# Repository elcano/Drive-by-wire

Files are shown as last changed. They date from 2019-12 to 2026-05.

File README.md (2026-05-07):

# DriveByWire

Obsolete. New code is in DBW version 5.

This repository is for use with the **Drive by Wire** board created to be used for the ELCANO self-driving tricycle. In order for this module to run external libraries are required.

Repositories were updated 6/8/2023 but clobbered previous history. Chief addition is use of an RC controller that allows manual control of throttle, brakes and steering.
The Sender files are intended for use on the Hi-Level board and do not really belong in the Drive-by-wire repository.

Libraries needed are listed below:

ALL Versions ________________________________
* PID by Brett Beauregard
    https://github.com/br3ttb/Arduino-PID-Library
    A simple controller calculator (proportional integral derivative) to calculate the error between a desired output and an actual output. Has files **PID_v1**

Version 3 (Arduino Mega) ________________________________
* CAN_BUS_SHIELD by Seeed-Studio
    https://github.com/Seeed-Studio/CAN_BUS_Shield
    Contains CAN_BUS communication protocols and required files such as **mcp_can** and **can-serial**

* Pin Change Interrupt by Nico Hood
    https://github.com/NicoHood/PinChangeInterrupt
    For custom configuration of Arduino pin properties. Has files **PinChangeInterupt**

* MCP48x2 DAC by Jonas Forsberg
    https://github.com/SweBarre/MCP48x2.
    Library for Digital to anolog converter. Has files **MCP48x2**

Version 4 (Arduino Due)  _______________________________________________
* Due CAN and CAN Common by Collin Kidder
    https://github.com/collin80/due_can
    https://github.com/collin80/can_common

## To Install

* Download the **Drive_By_Wire** module into the project parent directory
```
git clone https://github.com/elcano/Drive-by-wire.git
```
* Move into the **Drive_By_Wire** folder
```
cd Drive_By_Wire
```
* Download the required libraries
```
git clone https://github.com/Seeed-Studio/Seeed_Arduino_CAN.git
git clone https://github.com/br3ttb/Arduino-PID-Library.git
git clone https://github.com/NicoHood/PinChangeInterrupt.git
git clone https://github.com/SweBarre/MCP48x2.git
git clone https://github.com/ivanseidel/DueTimer.git
git clone https://github.com/collin80/can_common.git
git clone https://github.com/collin80/due_can.git
```
* Add the folders above to the IDE directory. In Windows, add the required libraries to: C:\Users\<username>\Documents\Arduino\libraries
* Arduino Due requires additional installation. On the IDE, go to Tools -> Boards -> Boards Manager -> Arduino SAM Boards (32-bits ARM Cortex-M3) 

## Navigating Arduino IDE: 
* **Selecting Board:** Tools -> Board -> Arduino AVR/SAM Boards -> Arduino Mega/Due
* **Selecting Serial Port:** Tools -> Port -> COM (Arduino Mega/Due)
* **Accessing Serial Monitor:** Right-hand Corner -> Select Baud Rate (115200)

## Drive-by-Wire: 
* **Low-level board code with RC control support with existing code for brakes, steering, and throttle.** 

## Test: 
* **Low-level board code with three functions to test each subsystems individually (brakes, steering, throttle).** 
* testBrake(): Activates brakes with 24V via Stop(), Holds brakes with 12V after 800ms via Update(), Releases brakes every ~2 seconds.
* testThrottle(): Gradually increases speed and decreases speed on DACA.
* testSteering(): Changes directions every 3 seconds, moving the linear actuator. 

## Sender: 
* **High-level board code to communicate with low-level board using CAN communication.** 
* Arguments for Function: Each data is reserved for 2 bytes. 
    *   currentSpeed: Controls the speed via the DACA, input: (0 -255).
    *   currentBrake: Apply and updates brakes if necessary, input: (0 - releases brakes, anything above 0 - applies brakes).
    *   currentAngle: Changes direction based on input (may need to calibrate based on sensors), left: 779 (1ms), middle: 722 (1.5ms), right: 639 (1.85ms).

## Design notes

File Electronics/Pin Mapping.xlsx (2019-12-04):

Mega2560 Pin Number | Mega2560 Pin Name | Arduino Pin Name | Second Draft LLBV3 Pin Name | LLBV3 Header / Function
1 | PG5 ( OC0B ) | Digital pin 4 (PWM)
2 | PE0 ( RXD0/PCINT8 ) | Digital pin 0 (RX0) | RX0 | USB Serial
3 | PE1 ( TXD0 ) | Digital pin 1 (TX0) | TX0 | USB Serial
4 | PE2 ( XCK0/AIN0 )
5 | PE3 ( OC3A/AIN1 ) | Digital pin 5 (PWM) | WATCHDOG | X3, for power on board
6 | PE4 ( OC3B/INT4 ) | Digital pin 2 (PWM) | Brake_PWM | X3, for power on board
7 | PE5 ( OC3C/INT5 ) | Digital pin 3 (PWM)
8 | PE6 ( T3/INT6 )
9 | PE7 ( CLKO/ICP3/INT7 )
10 | VCC | VCC
11 | GND | GND
12 | PH0 ( RXD2 ) | Digital pin 17 (RX2)
13 | PH1 ( TXD2 ) | Digital pin 16 (TX2)
14 | PH2 ( XCK2 )
15 | PH3 ( OC4A ) | Digital pin 6 (PWM)
16 | PH4 ( OC4B ) | Digital pin 7 (PWM) | STEER_SERVO_PWM | Steering header
17 | PH5 ( OC4C ) | Digital pin 8 (PWM)
18 | PH6 ( OC2B ) | Digital pin 9 (PWM)
19 | PB0 ( SS/PCINT0 ) | Digital pin 53 (SS) | SPI_SLAVE | SPI header (this pin tells the mega to be a slave)
20 | PB1 ( SCK/PCINT1 ) | Digital pin 52 (SCK) | SCK | all SPI devices, SPI header
21 | PB2 ( MOSI/PCINT2 ) | Digital pin 51 (MOSI) | MOSI | all SPI devices, SPI header
22 | PB3 ( MISO/PCINT3 ) | Digital pin 50 (MISO) | MISO | all SPI devices, SPI header
23 | PB4 ( OC2A/PCINT4 ) | Digital pin 10 (PWM)
24 | PB5 ( OC1A/PCINT5 ) | Digital pin 11 (PWM)
25 | PB6 ( OC1B/PCINT6 ) | Digital pin 12 (PWM)
26 | PB7 ( OC0A/OC1C/PCINT7 ) | Digital pin 13 (PWM)
27 | PH7 ( T4 )
28 | PG3 ( TOSC2 )
29 | PG4 ( TOSC1 )
30 | RESET | RESET
31 | VCC | VCC
32 | GND | GND
33 | XTAL2 | XTAL2
34 | XTAL1 | XTAL1
35 | PL0 ( ICP4 ) | Digital pin 49 | CAN_SS | MCP2515 slave selection
36 | PL1 ( ICP5 ) | Digital pin 48 | DAC_SS | DAC slave selection
37 | PL2 ( T5 ) | Digital pin 47
38 | PL3 ( OC5A ) | Digital pin 46 (PWM)
39 | PL4 ( OC5B ) | Digital pin 45 (PWM)
40 | PL5 ( OC5C ) | Digital pin 44 (PWM)
41 | PL6 | Digital pin 43
42 | PL7 | Digital pin 42
43 | PD0 ( SCL/INT0 ) | Digital pin 21 (SCL)
44 | PD1 ( SDA/INT1 ) | Digital pin 20 (SDA)
45 | PD2 ( RXDI/INT2 ) | Digital pin 19 (RX1)
46 | PD3 ( TXD1/INT3 ) | Digital pin 18 (TX1)
47 | PD4 ( ICP1 )
48 | PD5 ( XCK1 )
49 | PD6 ( T1 )
50 | PD7 ( T0 ) | Digital pin 38
51 | PG0 ( WR ) | Digital pin 41 | BRAKE_ON | on-board relay
52 | PG1 ( RD ) | Digital pin 40 | BUZZER | on-board buzzer
53 | PC0 ( A8 ) | Digital pin 37 | VOLTAGE_SWITCH | on-board relay
54 | PC1 ( A9 ) | Digital pin 36 | D_36 | X3, no purpose assgined
55 | PC2 ( A10 ) | Digital pin 35
56 | PC3 ( A11 ) | Digital pin 34 | FWDSW | X3, for power on board
57 | PC4 ( A12 ) | Digital pin 33
58 | PC5 ( A13 ) | Digital pin 32
59 | PC6 ( A14 ) | Digital pin 31
60 | PC7 ( A15 ) | Digital pin 30
61 | VCC | VCC
62 | GND | GND
63 | PJ0 ( RXD3/PCINT9 ) | Digital pin 15 (RX3) | RX3 | X3, for power on board
64 | PJ1 ( TXD3/PCINT10 ) | Digital pin 14 (TX3) | TX3 | X3, for power on board
65 | PJ2 ( XCK3/PCINT11 )
66 | PJ3 ( PCINT12 )
67 | PJ4 ( PCINT13 )
68 | PJ5 ( PCINT14 )
69 | PJ6 ( PCINT 15 )
70 | PG2 ( ALE ) | Digital pin 39
71 | PA7 ( AD7 ) | Digital pin 29
72 | PA6 ( AD6 ) | Digital pin 28
73 | PA5 ( AD5 ) | Digital pin 27
74 | PA4 ( AD4 ) | Digital pin 26
75 | PA3 ( AD3 ) | Digital pin 25
76 | PA2 ( AD2 ) | Digital pin 24 | REVERSE | X3, for power on board
77 | PA1 ( AD1 ) | Digital pin 23
78 | PA0 ( AD0 ) | Digital pin 22 | REGEN_ACTIVE | X3, for power on board
79 | PJ7
80 | VCC | VCC
81 | GND | GND
82 | PK7 ( ADC15/PCINT23 ) | Analog pin 15 | HALLPHASEA (INT) | X3, for power on board
83 | PK6 ( ADC14/PCINT22 ) | Analog pin 14 | HALLPHASEB (INT) | X3, for power on board
84 | PK5 ( ADC13/PCINT21 ) | Analog pin 13 | EBIKECONTRL (INT) | X3, for power on board
85 | PK4 ( ADC12/PCINT20 ) | Analog pin 12 | HALLPHASEC (INT) | X3, for power on board
86 | PK3 ( ADC11/PCINT19 ) | Analog pin 11 | Speedometer (INT) | X3, for power on board
87 | PK2 ( ADC10/PCINT18 ) | Analog pin 10 | CAN_INT | MCP 2515 interrupt on received frames
88 | PK1 ( ADC9/PCINT17 ) | Analog pin 9 | E-stop (INT) | E-stop jumper, also X3
89 | PK0 ( ADC8/PCINT16 ) | Analog pin 8 | Wheel Rotation (INT) | wheel hall switch header
90 | PF7 ( ADC7 ) | Analog pin 7 | R_RTN_GND | Steering header
91 | PF6 ( ADC6 ) | Analog pin 6 | L_RTN_GND | Steering header
92 | PF5 ( ADC5/TMS ) | Analog pin 5
93 | PF4 ( ADC4/TMK ) | Analog pin 4
94 | PF3 ( ADC3 ) | Analog pin 3 | R_SENSE | Steering header
95 | PF2 ( ADC2 ) | Analog pin 2 | L_SENSE | Steering header
96 | PF1 ( ADC1 ) | Analog pin 1
97 | PF0 ( ADC0 ) | Analog pin 0
98 | AREF | Analog Reference
99 | GND | GND
100 | AVCC | VCC

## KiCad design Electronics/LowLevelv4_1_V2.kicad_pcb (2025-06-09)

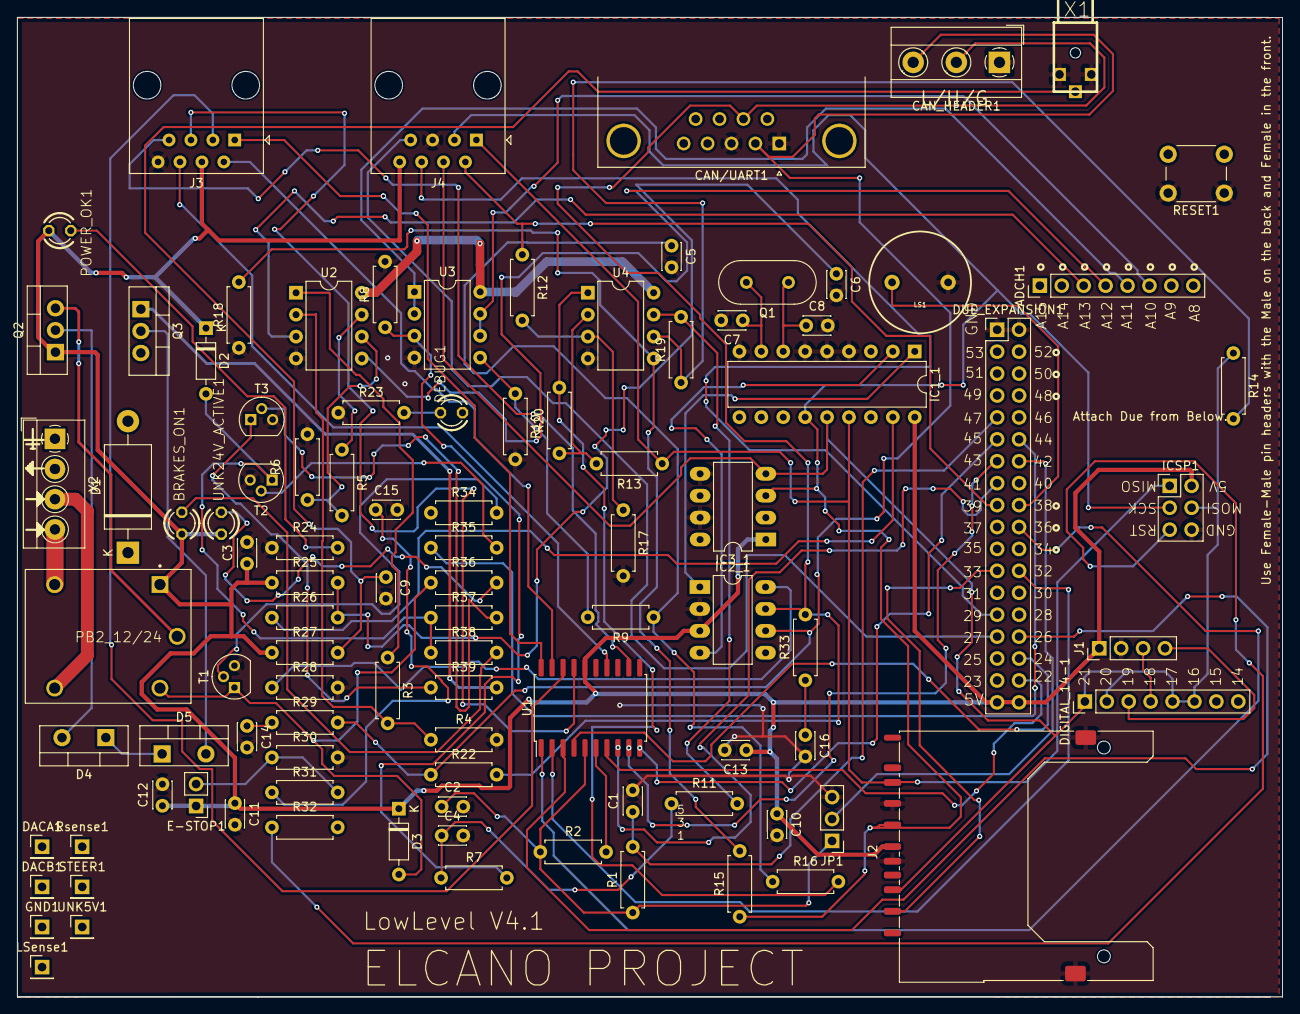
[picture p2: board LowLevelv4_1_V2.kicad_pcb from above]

Board: 2 copper layers, 146.6 x 113.5 mm, 100 parts (0 on the bottom side), 80 nets.

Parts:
ADCH1: Analog In 8-11, DAC, CAN; PinHeader_1x08_P2.54mm_Vertical
BRAKES_ON1: LED3MM
C1, C9, C15: 1uF; C_Disc_D3.0mm_W2.0mm_P2.50mm
C2, C3, C4, C5, C6, C10, C11, C12, C13: 0.1uF; C_Disc_D3.0mm_W2.0mm_P2.50mm
C7, C8: 33pF; C_Disc_D3.0mm_W2.0mm_P2.50mm
C14, C16: 560pF; C_Disc_D3.0mm_W2.0mm_P2.50mm
CAN/UART1: DB9 Plug; DSUB-9_Male_Horizontal_P2.77x2.84mm_EdgePinOffset4.94mm_Hou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
CAN_HEADER1: CONN_03-SCREW-5MM; TerminalBlock_MetzConnect_Type055_RT01503HDWU_1x03_P5.00mm_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
D1: 1N5400; D_DO-201_P15.24mm_Horizontal
D2, D3: 1N4148; D_DO-35_SOD27_P7.62mm_Horizontal
D4, D5: MBR745; TO-220-2_Vertical
DACA1: PTR1PAD1-17; PinHeader_1x01_P2.54mm_Vertical
DACB1: PTR1PAD1-17; PinHeader_1x01_P2.54mm_Vertical
DEBUG1: LED3MM
DIGITAL_14-1: Digital 14-21; PinHeader_1x08_P2.54mm_Vertical
DUE_EXPANSION1: Digital 22-53; PinHeader_2x18_P2.54mm_Vertical
E-STOP1: PINHD-1X2; PinHeader_1x02_P2.54mm_Vertical
GND1: PTR1PAD1-17; PinHeader_1x01_P2.54mm_Vertical
IC1_1: MCP2515(MCP2510)P; DIP-18_W7.62mm
IC2_1: MCP2551DIL08; DIP-8_W7.62mm_LongPads
IC3_1: MCP4802; DIP-8_W7.62mm_LongPads
ICSP1: 2x3; PinHeader_2x03_P2.54mm_Vertical
J1: ROS_CONN; PinHeader_1x04_P2.54mm_Vertical
J2: SD_Card; SD_Kyocera_145638109511859+
J3: RJ45_MOTOR; RJ45_Amphenol_54602-x08_Horizontal
J4: RJ45_STEER; RJ45_Amphenol_54602-x08_Horizontal
JP1: Jumper_3_Open; PinHeader_1x03_P2.54mm_Vertical
LS1: BUZZER-PTH; BUZZER-12MM
LSense1: PTR1PAD1-17; PinHeader_1x01_P2.54mm_Vertical
PB2_12/24: ORWH-SH-105D1F,000; TE_ORWH-SH-105D1F,000
POWER_OK1: LED3MM
Q1: ECS-160-20-46X; Crystal_HC49-U_Vertical
Q2, Q3: IRLZ44N; TO-220-3_Vertical
R1, R11, R16: 4.7k; R_Axial_DIN0207_L6.3mm_D2.5mm_P7.62mm_Horizontal
R2, R4, R8, R30, R31: 10k; R_Axial_DIN0207_L6.3mm_D2.5mm_P7.62mm_Horizontal
R3, R5, R6, R7, R9, R10: 5.15k; R_Axial_DIN0207_L6.3mm_D2.5mm_P7.62mm_Horizontal
R12, R13, R14, R15, R17, R18, R19, R20: 22k; R_Axial_DIN0207_L6.3mm_D2.5mm_P7.62mm_Horizontal
R22: 120; R_Axial_DIN0207_L6.3mm_D2.5mm_P7.62mm_Horizontal
R23, R24, R26, R34, R35, R36, R38: 1K; R_Axial_DIN0207_L6.3mm_D2.5mm_P7.62mm_Horizontal
R25: 20K; R_Axial_DIN0207_L6.3mm_D2.5mm_P7.62mm_Horizontal
R27, R28: 4.7K; R_Axial_DIN0207_L6.3mm_D2.5mm_P7.62mm_Horizontal
R29, R33, R39: 100; R_Axial_DIN0207_L6.3mm_D2.5mm_P7.62mm_Horizontal
R32: 0; R_Axial_DIN0207_L6.3mm_D2.5mm_P7.62mm_Horizontal
R37: 1k; R_Axial_DIN0207_L6.3mm_D2.5mm_P7.62mm_Horizontal
RESET1: MOMENTARY-SWITCH-SPST-PTH-6.0MM; SW_PUSH_6mm
Rsense1: PTR1PAD1-17; PinHeader_1x01_P2.54mm_Vertical
STEER1: PTR1PAD1-17; PinHeader_1x01_P2.54mm_Vertical
T1, T2, T3: 2N3904; TO-92
U1: TXB0108DQSR; SOIC-20W_7.5x12.8mm_P1.27mm
U2, U3, U4: LM358; DIP-8_W7.62mm
UNK5V1: PTR1PAD1-17; PinHeader_1x01_P2.54mm_Vertical
UNK24V_ACTIVE1: LED3MM
X1: ODO_JACK
X2: TerminalBlock_4Ucon_1x04_P3.50mm_Horizontal

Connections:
+3.3V: C2.1, JP1.1 (A), R1.1, R2.1, U1.5 (VCCA)
+5V: BRAKES_ON1.A, C3.1, C10.1, C11.1, C12.1, C13.1, D2.1 (K), D3.1 (K), DUE_EXPANSION1.35, DUE_EXPANSION1.36, E-STOP1.1, IC1_1.18 (VDD), IC2_1.3 (VDD), IC3_1.1, ICSP1.2, J1.1 (5V), J2.4 (VDD), J3.4, J4.8, PB2_12/24.1 (C1), POWER_OK1.A, Q2.1 (G), R25.1, R27.1, U1.16 (VCCB), UNK24V_ACTIVE1.A
+12V: U2.8 (V+), U3.8 (V+), U4.8 (V+)
/Low Level 4.1 Segment 1/5V_DAC1: R3.1, U2.1
/Low Level 4.1 Segment 1/5V_FWDSW: J3.1, U1.20 (B1)
/Low Level 4.1 Segment 1/5V_REGEN: J3.6, U1.14 (B5)
/Low Level 4.1 Segment 1/5V_REVERSE: J3.5, U1.17 (B4)
/Low Level 4.1 Segment 1/5V_SPEEDOMETER: J3.7, U1.12 (B7)
/Low Level 4.1 Segment 1/5V_STEER_PULSE: J3.3, U1.18 (B3)
/Low Level 4.1 Segment 1/5V_THROTTLE: R5.1, U2.7
/Low Level 4.1 Segment 1/5V_WATCHDOG: J3.2, U1.19 (B2)
/Low Level 4.1 Segment 1/BRAKE_PULSE: DUE_EXPANSION1.15, U1.8 (A6)
/Low Level 4.1 Segment 1/CAN_ENABLE: DUE_EXPANSION1.14, JP1.2 (C)
/Low Level 4.1 Segment 1/CHIP_SELECT_ANGLE: DUE_EXPANSION1.17, J4.2, R12.1
/Low Level 4.1 Segment 1/CHIP_SELECT_SD: DUE_EXPANSION1.23, J2.1 (CD/DAT3)
/Low Level 4.1 Segment 1/DAC1: ADCH1.3, U2.3 (+)
/Low Level 4.1 Segment 1/EBIKE_POWER_IN: DUE_EXPANSION1.11, U1.10 (A8)
/Low Level 4.1 Segment 1/FWDSW: DUE_EXPANSION1.20, U1.1 (A1)
/Low Level 4.1 Segment 1/IRPT_WHEEL: C1.1, DUE_EXPANSION1.9, R1.2
/Low Level 4.1 Segment 1/REGEN: DUE_EXPANSION1.34, U1.7 (A5)
/Low Level 4.1 Segment 1/REVERSE: DUE_EXPANSION1.32, U1.4 (A4)
/Low Level 4.1 Segment 1/RX1_DBW: DIGITAL_14-1.3, J1.4 (RX1)
/Low Level 4.1 Segment 1/R_SENSE: ADCH1.5, U3.1, U3.2 (-)
/Low Level 4.1 Segment 1/SPEEDOMETER: DUE_EXPANSION1.13, U1.9 (A7)
/Low Level 4.1 Segment 1/STEER_PULSE/L_TURN: DUE_EXPANSION1.30, U1.3 (A3)
/Low Level 4.1 Segment 1/THROTTLE_DAC0: ADCH1.4, U2.5 (+)
/Low Level 4.1 Segment 1/TX1_DBW: DIGITAL_14-1.4, J1.3 (TX1)
/Low Level 4.1 Segment 1/WATCHDOG: DUE_EXPANSION1.24, U1.2 (A2)
/Low Level 4.1 Segment 2/CAN_RXD: IC1_1.2 (RXCAN), IC2_1.4 (RXD)
/Low Level 4.1 Segment 2/CAN_TXD: IC1_1.1 (TXCAN), IC2_1.1 (TXD)
/Low Level 4.1 Segment 2/OSC1: C7.1, IC1_1.8 (OSC1), Q1.2
/Low Level 4.1 Segment 2/OSC2: C8.1, IC1_1.7 (OSC2), Q1.1
/Low Level 4.1 Segment 2/RS: IC1_1.17 (RESET), R26.1
/Low Level 4.1 Segment 3/SOLENOID_OUT: D4.1 (K), D5.1 (K)
/Low Level 4.1 Segment 3/SOLENOID_POWER: PB2_12/24.3 (C), Q2.3 (S)
BRAKE_ON: DUE_EXPANSION1.12, R35.1
BUZZER: DUE_EXPANSION1.18, LS1.+ (1)
CANH: CAN/UART1.7, CAN_HEADER1.2, IC2_1.7 (CANH), R22.2, R33.2
CANL: CAN/UART1.2, CAN_HEADER1.3, IC2_1.6 (CANL), R22.1, R29.2
ESTOP_INT: C15.1, R31.1
GND: C1.2, C2.2, C3.2, C4.2, C5.2, C6.2, C7.2, C8.2, C9.2, C10.2, C11.2, C12.2, C13.2, C14.2, C15.2, C16.2, CAN/UART1.1, CAN/UART1.3, CAN_HEADER1.1, DUE_EXPANSION1.1, DUE_EXPANSION1.2, IC1_1.4 (TX0RTS), IC1_1.5 (TX1RTS), IC1_1.6 (TX2RTS), IC1_1.9 (VSS), IC2_1.2 (VSS), IC3_1.5, IC3_1.7, ICSP1.6, J1.2 (GND), J2.3 (VSS), J2.6 (VSS), J2.12 (SHELL1), J2.13 (SHELL2), J3.8, J4.5, JP1.3 (B), LS1.- (2), R4.2, R6.2, R8.2, R10.2, R17.2, R18.1, R23.1, R24.1, R28.2, R30.2, RESET1.1, T1.3 (E), T2.3 (E), T3.3 (E), U1.15 (GND), U2.4 (V-), U3.4 (V-), U4.4 (V-), X1.P$2 (2), X1.P$3 (3)
L_SENSE: ADCH1.6, U3.6 (-), U3.7
L_TN: DUE_EXPANSION1.29, J4.7
MISO: IC1_1.15 (SO), ICSP1.1, J2.7 (DAT0), J4.1, R13.1
MOSI: DIGITAL_14-1.1, DIGITAL_14-1.2, DIGITAL_14-1.5, DIGITAL_14-1.6, IC1_1.14 (SI), IC3_1.4, ICSP1.4, J2.2 (CMD), J4.4, R14.1
unnamed: BRAKES_ON1.K (C), R38.2
unnamed: C4.1, R7.1, R11.1
unnamed: C5.1, R9.1, R16.1
unnamed: C6.1, R25.2, R26.2
unnamed: C14.1, R29.1
unnamed: C16.1, R33.1
unnamed: D2.2 (A), R37.1, R38.1, T2.1 (C)
unnamed: D3.2 (A), PB2_12/24.2 (C2), R36.1, T1.1 (C)
unnamed: D4.2 (A), Q2.2 (D)
unnamed: D5.2 (A), Q3.2 (D)
unnamed: DEBUG1.K (C), R23.2
unnamed: E-STOP1.2, R30.1, R31.2
unnamed: IC2_1.8 (RS), R28.1
unnamed: POWER_OK1.K (C), R24.2
unnamed: Q3.1 (G), R39.2
unnamed: R11.2, R19.2, U4.7
unnamed: R16.2, R20.2, U4.1
unnamed: R34.2, T1.2 (B)
unnamed: R35.2, T2.2 (B)
unnamed: R37.2, T3.2 (B)
unnamed: R39.1, T3.1 (C)
unnamed: R2.2, U1.6 (OE)
unnamed: R3.2, R4.1, U2.2 (-)
unnamed: R5.2, R6.1, U2.6 (-)
unnamed: R7.2, R8.1, U3.3 (+)
unnamed: R9.2, R10.1, U3.5 (+)
unnamed: R12.2, R17.1, U4.3 (+)
unnamed: R13.2, R20.1, U4.2 (-)
unnamed: R15.2, R18.2, U4.5 (+)
unnamed: R14.2, R19.1, U4.6 (-)
unnamed: R36.2, UNK24V_ACTIVE1.K (C)
RESET: ICSP1.5, R32.1
R_TN: DUE_EXPANSION1.27, J4.6
SCK: IC1_1.13 (SCK), IC3_1.3, ICSP1.3, J2.5 (CLK), J4.3, R15.1
WHEELROTATION: C9.1, R27.2, X1.P$1 (1)

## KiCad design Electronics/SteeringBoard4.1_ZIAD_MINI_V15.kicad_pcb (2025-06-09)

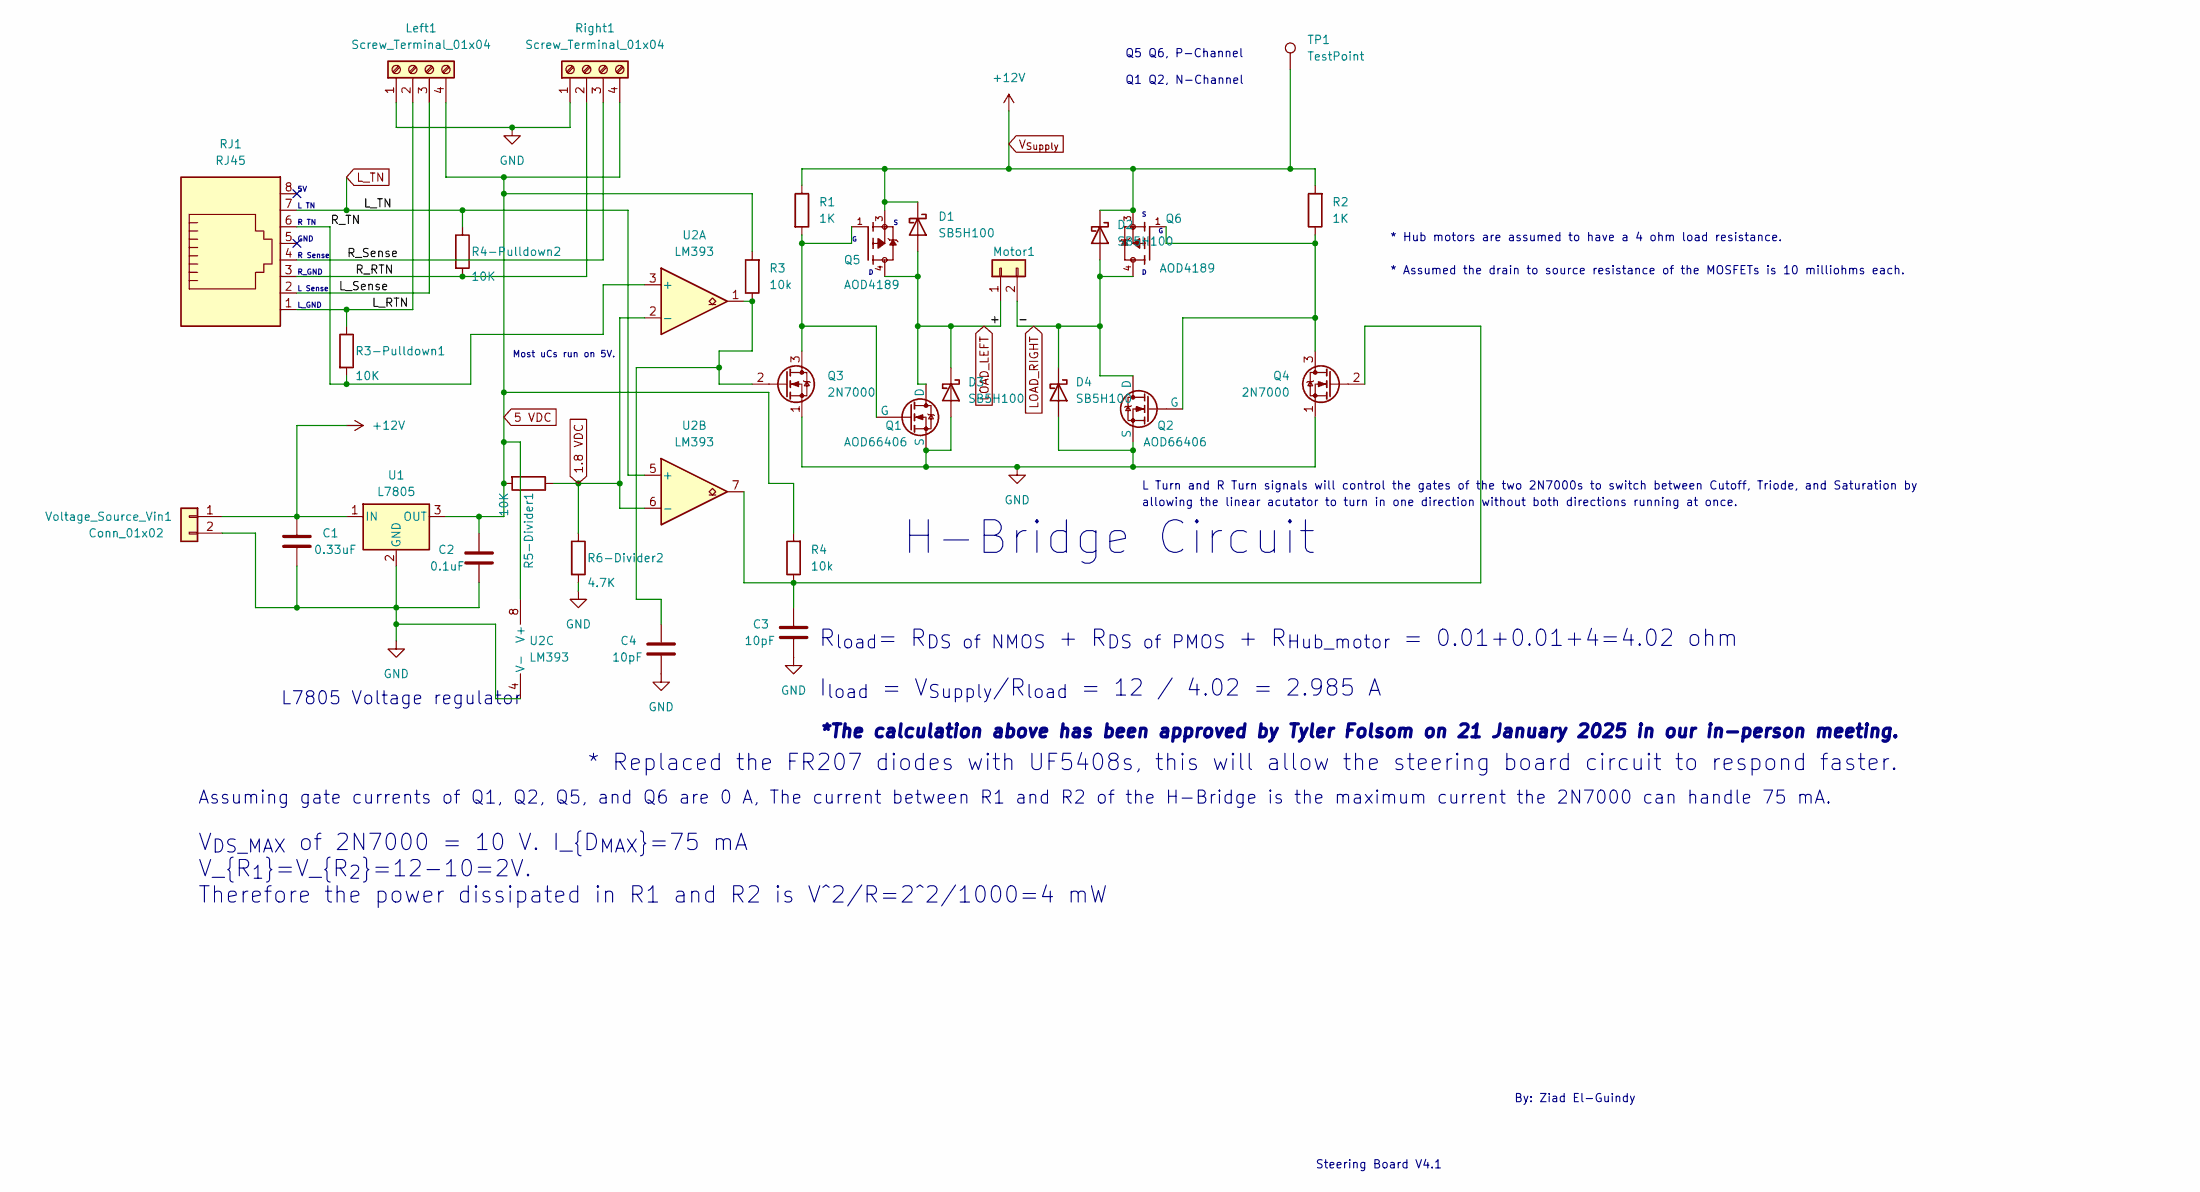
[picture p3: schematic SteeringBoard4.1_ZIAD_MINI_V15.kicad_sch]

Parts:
C1: 0.33uF; C_Radial_D5.0mm_H7.0mm_P2.00mm
C2: 0.1uF; C_Radial_D5.0mm_H7.0mm_P2.00mm
C3, C4: 10pF; C_Radial_D5.0mm_H7.0mm_P2.00mm
D1, D2, D3, D4: SB5H100; D_DO-201AD_P15.24mm_Horizontal
Left1: Screw_Terminal_01x04; TerminalBlock_MetzConnect_Type059_RT06304HBWC_1x04_P3.50mm_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
Motor1: Conn_01x02; Anderson_Conn
Q1, Q2: AOD66406
Q3, Q4: 2N7000; TO-92_Inline
Q5, Q6: AOD4189; DPACK
R1, R2: 1K; R_Axial_DIN0414_L11.9mm_D4.5mm_P15.24mm_Horizontal
R3, R4: 10k; R_Axial_DIN0204_L3.6mm_D1.6mm_P5.08mm_Horizontal
R3-Pulldown1, R4-Pulldown2, R5-Divider1: 10K; R_Axial_DIN0204_L3.6mm_D1.6mm_P5.08mm_Horizontal
R6-Divider2: 4.7K; R_Axial_DIN0204_L3.6mm_D1.6mm_P5.08mm_Horizontal
RJ1: RJ45; RJ45_Amphenol_54602-x08_Horizontal
Right1: Screw_Terminal_01x04; TerminalBlock_MetzConnect_Type059_RT06304HBWC_1x04_P3.50mm_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
TP1: TestPoint; Pin_D1.0mm_L10.0mm
U1: L7805; TO-220-3_Vertical
U2: LM393; DIP-8_W7.62mm
Voltage_Source_Vin1: Conn_01x02; Anderson_Conn

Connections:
1.8 VDC: R5-Divider1.1, R6-Divider2.1, U2.2 (-), U2.6 (-)
5 VDC: C2.1, Left1.4, R3.2, R4.2, R5-Divider1.2, Right1.4, U1.3 (OUT), U2.8 (V+)
/L_RTN: Left1.2, R3-Pulldown1.1, RJ1.1
/L_Sense: Left1.3, RJ1.2
/R_RTN: R4-Pulldown2.2, RJ1.3, Right1.2
/R_Sense: RJ1.4, Right1.3
/R_TN: R3-Pulldown1.2, RJ1.6, U2.3 (+)
GND: C1.2, C2.2, C3.2, C4.2, D3.2 (A), D4.2 (A), Left1.1, Q1.3 (S), Q2.3 (S), Q3.1 (S), Q4.1 (S), R6-Divider2.2, Right1.1, U1.2 (GND), U2.4 (V-), Voltage_Source_Vin1.2
LOAD_LEFT: D1.2 (A), D3.1 (K), Motor1.1, Q1.1 (D), Q5.4
LOAD_RIGHT: D2.2 (A), D4.1 (K), Motor1.2, Q2.1 (D), Q6.4
L_TN: R4-Pulldown2.1, RJ1.7, U2.5 (+)
unnamed: Q1.2 (G), Q3.3 (D), Q5.1, R1.2
unnamed: Q2.2 (G), Q4.3 (D), Q6.1, R2.1
unnamed: C4.1, Q3.2 (G), R3.1, U2.1
unnamed: C3.1, Q4.2 (G), R4.1, U2.7
V_{Supply}: C1.1, D1.1 (K), D2.1 (K), Q5.3, Q6.3, R1.1, R2.2, TP1.1, U1.1 (IN), Voltage_Source_Vin1.1

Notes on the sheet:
R Sense
R TN
GND
V_{DS_MAX} of 2N7000 = 10 V. I_{D_{MAX}}=75 mA V_{R_{1}}=V_{R_{2}}=12-10=2V. Therefore the power dissipated in R1 and R2 is V^2/R=2^2/1000=4 mW
Steering Board V4.1
R_{load}= R_{DS of NMOS} + R_{DS of PMOS} + R_{Hub_motor} = 0.01+0.01+4=4.02 ohm
* Assumed the drain to source resistance of the MOSFETs is 10 milliohms each.
I_{load} = V_{Supply}/R_{load} = 12 / 4.02 = 2.985 A
Assuming gate currents of Q1, Q2, Q5, and Q6 are 0 A, The current between R1 and R2 of the H-Bridge is the maximum current the 2N7000 can handle 75 mA.
* Hub motors are assumed to have a 4 ohm load resistance.
* Replaced the FR207 diodes with UF5408s, this will allow the steering board circuit to respond faster.
allowing the linear acutator to turn in one direction without both directions running at once.
L TN
L Turn and R Turn signals will control the gates of the two 2N7000s to switch between Cutoff, Triode, and Saturation by
H-Bridge Circuit
Most uCs run on 5V.
*The calculation above has been approved by Tyler Folsom on 21 January 2025 in our in-person meeting.
L_GND
L Sense
Q5 Q6, P-Channel Q1 Q2, N-Channel
By: Ziad El-Guindy
R_GND
L7805 Voltage regulator

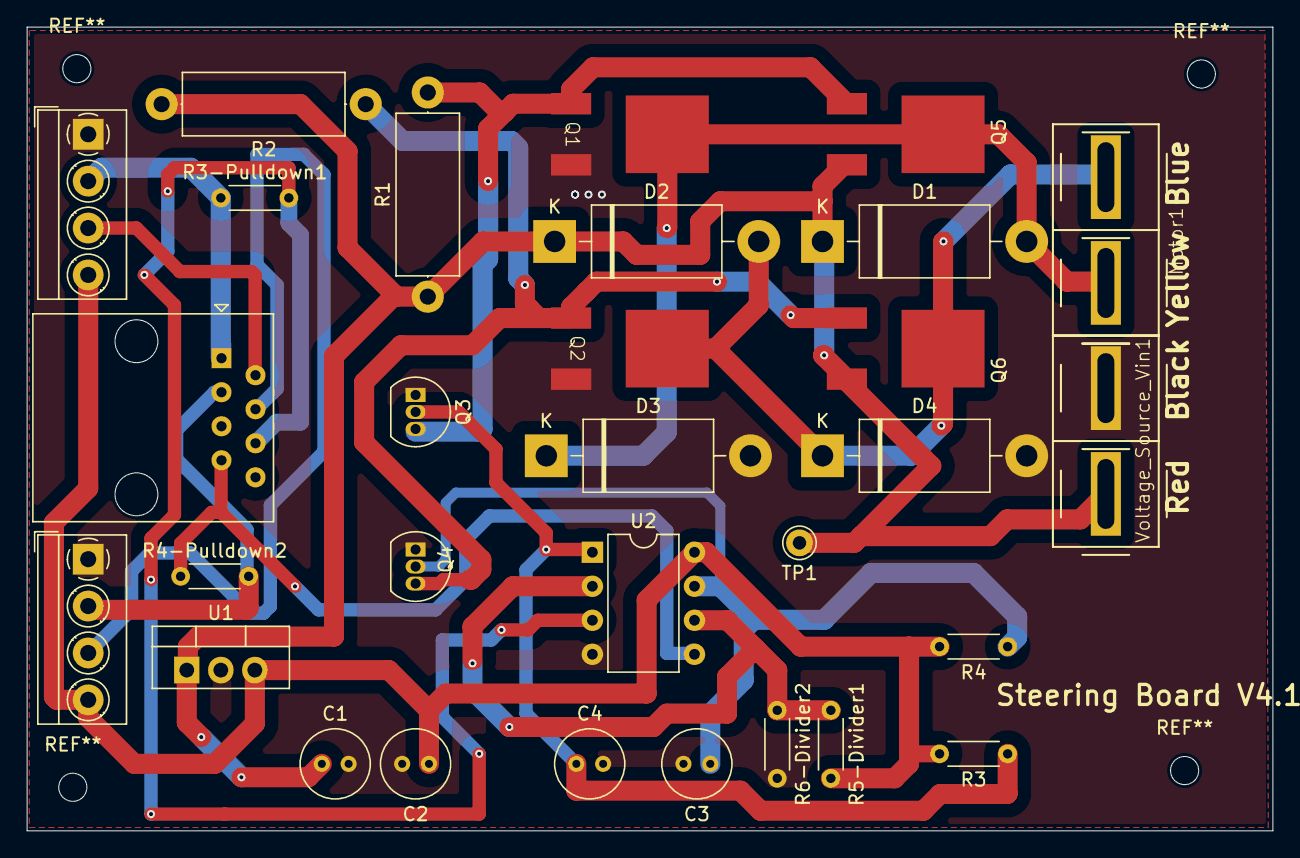
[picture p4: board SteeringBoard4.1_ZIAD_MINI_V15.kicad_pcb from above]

Board: 2 copper layers, 93.0 x 60.0 mm, 30 parts (0 on the bottom side), 16 nets.

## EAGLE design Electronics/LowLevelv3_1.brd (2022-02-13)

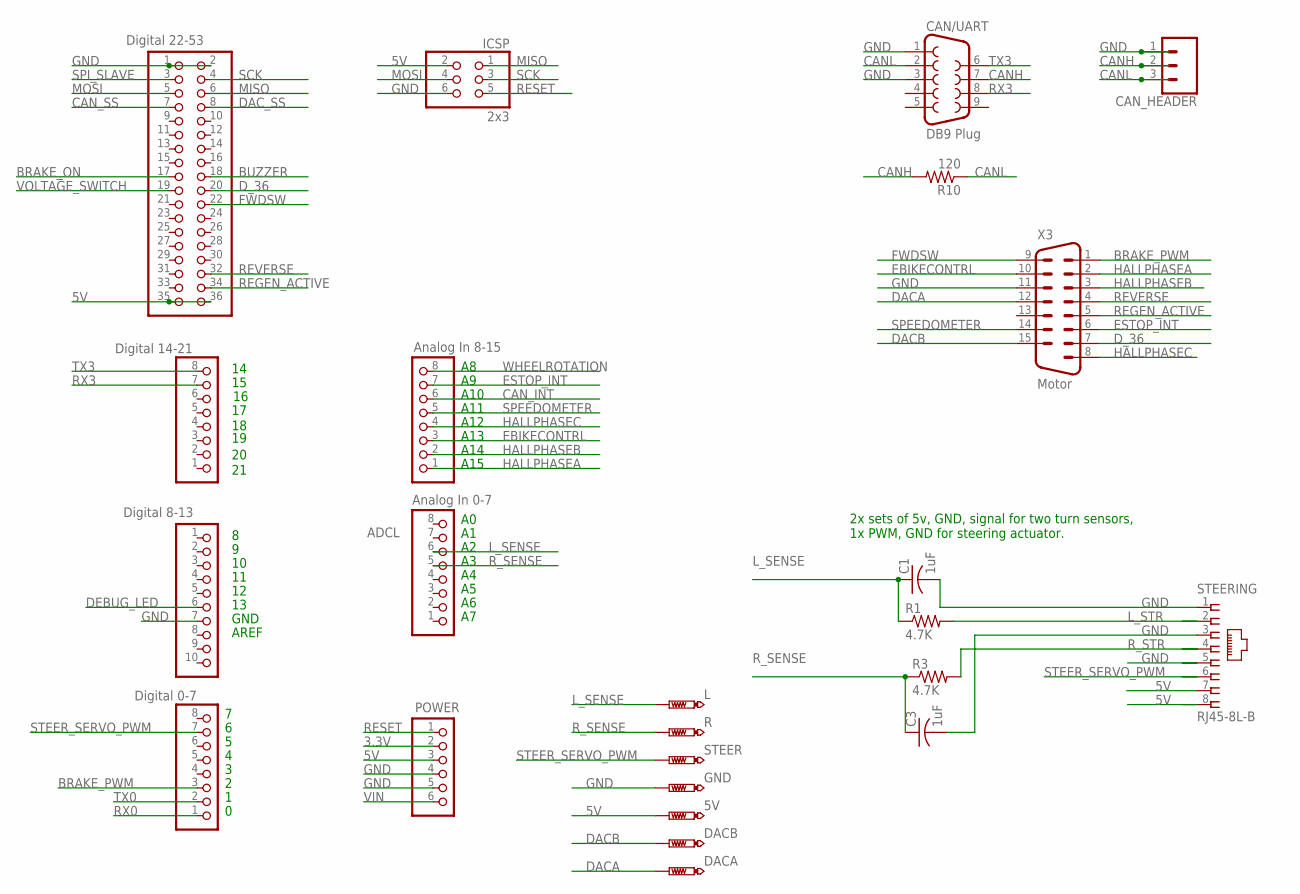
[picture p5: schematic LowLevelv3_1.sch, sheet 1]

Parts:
5V: PTR1PAD1-17; P1-17
ADCH: Analog In 8-15; 1X08
ADCL: Analog In 0-7; 1X08
C1, C3: 1uF; C1206
CAN/UART: DB9 Plug; DB9
CAN_HEADER: CONN_03-SCREW-5MM; SCREWTERMINAL-5MM-3
DACA: PTR1PAD1-17; P1-17
DACB: PTR1PAD1-17; P1-17
DIGITAL_0-7: Digital 0-7; 1X08
DIGITAL_8-13: Digital 8-13; 1X10
DIGITAL_14-21: Digital 14-21; 1X08
GND: PTR1PAD1-17; P1-17
ICSP: 2x3; 2X03
L: PTR1PAD1-17; P1-17
MEGA_EXPANSION: Digital 22-53; PINHEAD_2X18
POWER: PINHD-1X6; 1X06
R: PTR1PAD1-17; P1-17
R1, R3: 4.7K; R1206
R10: 120; R1206
STEER: PTR1PAD1-17; P1-17
STEERING: RJ45-8L-B; RJ45-NO-SHIELD
X3: Motor; 182-015-MALE

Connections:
3.3V: POWER.2
5V: 5V.TP, ICSP.2, MEGA_EXPANSION.35, MEGA_EXPANSION.36, POWER.3, STEERING.7, STEERING.8; also elsewhere on the board
BRAKE_ON: MEGA_EXPANSION.17; also elsewhere on the board
BRAKE_PWM: DIGITAL_0-7.3, X3.1
BUZZER: MEGA_EXPANSION.18; also elsewhere on the board
CANH: CAN/UART.7, CAN_HEADER.2, R10.2; also elsewhere on the board
CANL: CAN/UART.2, CAN_HEADER.3, R10.1; also elsewhere on the board
CAN_INT: ADCH.6; also elsewhere on the board
CAN_SS: MEGA_EXPANSION.7; also elsewhere on the board
DACA: DACA.TP, X3.12; also elsewhere on the board
DACB: DACB.TP, X3.15; also elsewhere on the board
DAC_SS: MEGA_EXPANSION.8; also elsewhere on the board
DEBUG_LED: DIGITAL_8-13.6; also elsewhere on the board
D_36: MEGA_EXPANSION.20, X3.7
EBIKECONTRL: ADCH.3, X3.10
ESTOP_INT: ADCH.7, X3.6; also elsewhere on the board
FWDSW: MEGA_EXPANSION.22, X3.9
GND: C1.2, C3.2, CAN/UART.1, CAN/UART.3, CAN_HEADER.1, DIGITAL_8-13.7, GND.TP, ICSP.6, MEGA_EXPANSION.1, MEGA_EXPANSION.2, POWER.4, POWER.5, STEERING.1, STEERING.3, STEERING.5, X3.11; also elsewhere on the board
HALLPHASEA: ADCH.1, X3.2
HALLPHASEB: ADCH.2, X3.3
HALLPHASEC: ADCH.4, X3.8
L_SENSE: ADCL.6, C1.1, L.TP, R1.1
L_STR: R1.2, STEERING.2
MISO: ICSP.1, MEGA_EXPANSION.6; also elsewhere on the board
MOSI: ICSP.4, MEGA_EXPANSION.5; also elsewhere on the board
REGEN_ACTIVE: MEGA_EXPANSION.34, X3.5
RESET: ICSP.5, POWER.1; also elsewhere on the board
REVERSE: MEGA_EXPANSION.32, X3.4
RX0: DIGITAL_0-7.1
RX3: CAN/UART.8, DIGITAL_14-21.7
R_SENSE: ADCL.5, C3.1, R.TP, R3.1
R_STR: R3.2, STEERING.4
SCK: ICSP.3, MEGA_EXPANSION.4; also elsewhere on the board
SPEEDOMETER: ADCH.5, X3.14
SPI_SLAVE: MEGA_EXPANSION.3
STEER_SERVO_PWM: DIGITAL_0-7.7, STEER.TP, STEERING.6
TX0: DIGITAL_0-7.2
TX3: CAN/UART.6, DIGITAL_14-21.8
VIN: POWER.6
VOLTAGE_SWITCH: MEGA_EXPANSION.19; also elsewhere on the board
WHEELROTATION: ADCH.8; also elsewhere on the board

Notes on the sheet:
A10
A11
A12
A13
A14
A15
GND
AREF
2x sets of 5v, GND, signal for two turn sensors, 1x PWM, GND for steering actuator.

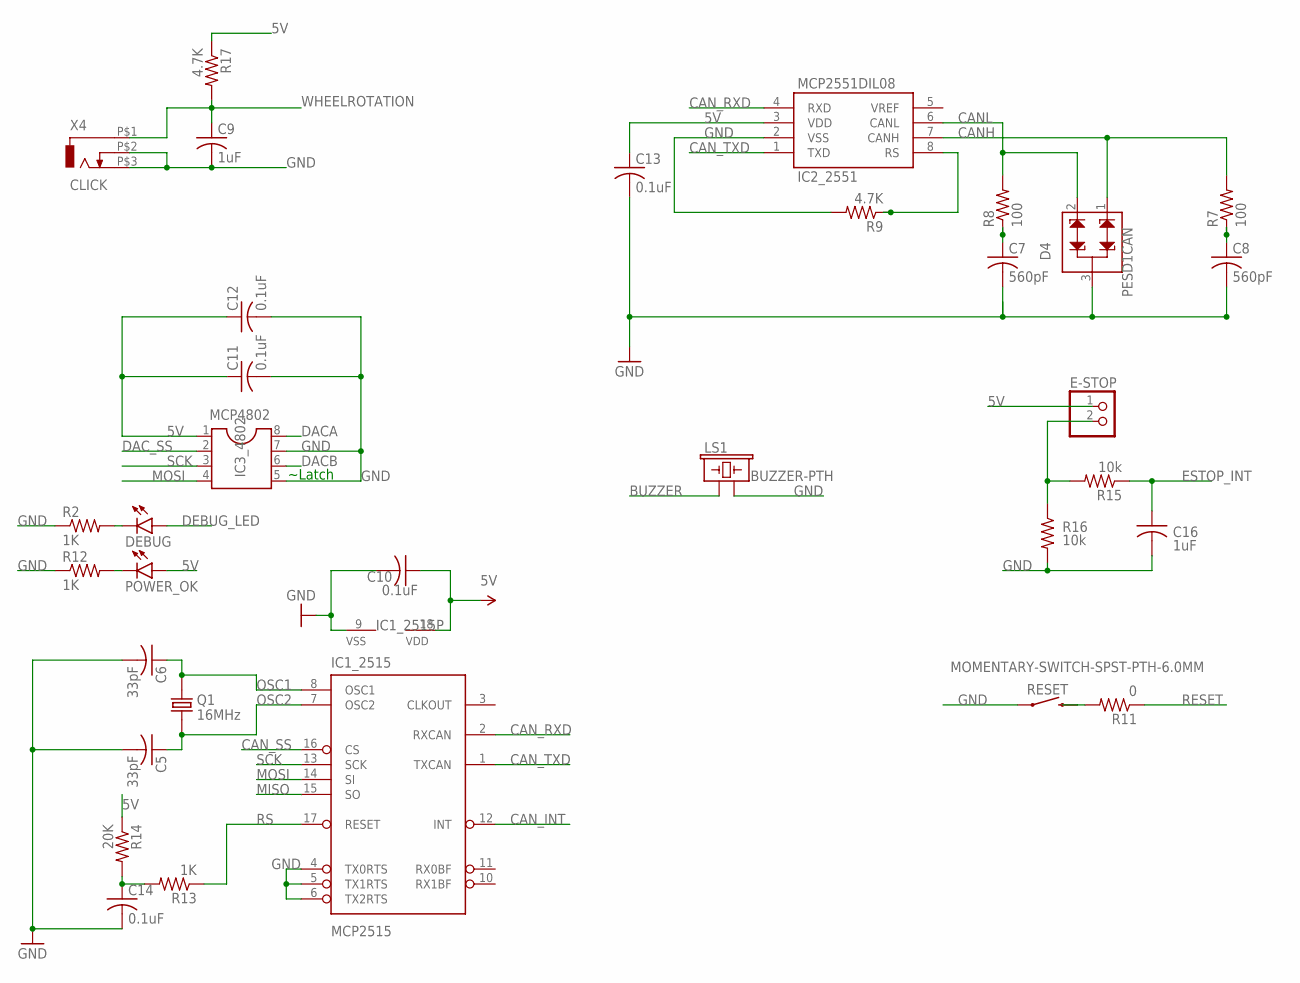
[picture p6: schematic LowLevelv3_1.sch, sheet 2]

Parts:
C5, C6: 33pF; C1206
C7, C8: 560pF; C1206
C9, C16: 1uF; C1206
C10, C11, C12, C13, C14: 0.1uF; C1206
D4: PESD1CAN; SPARKFUN-DISCRETESEMI_SOT23-3
DEBUG: LED3MM
E-STOP: PINHD-1X2; 1X02
IC1_2515: MCP2515; DIP18
IC2_2551: MCP2551DIL08; IC-PACKAGE_DIL08
IC3_4802: MCP4802; DIL08
LS1: BUZZER-PTH; BUZZER-12MM
POWER_OK: LED3MM
Q1: 16MHz; XTAL_ECS-160-20-46X
R2, R12, R13: 1K; R1206
R7, R8: 100; R1206
R9, R17: 4.7K; R1206
R11: 0; R1206
R14: 20K; R1206
R15, R16: 10k; R1206
RESET: MOMENTARY-SWITCH-SPST-PTH-6.0MM; TACTILE_SWITCH_PTH_6.0MM
X4: CLICK; ODO_JACK

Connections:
5V: C10.1, C11.1, C12.1, C13.1, E-STOP.1, IC1_2515.18 (VDD), IC2_2551.3 (VDD), IC3_4802.1, POWER_OK.A, R14.1, R17.1; also elsewhere on the board
BUZZER: LS1.+ (1); also elsewhere on the board
CANH: D4.1, IC2_2551.7 (CANH), R7.2; also elsewhere on the board
CANL: D4.2, IC2_2551.6 (CANL), R8.2; also elsewhere on the board
CAN_INT: IC1_2515.12 (INT); also elsewhere on the board
CAN_RXD: IC1_2515.2 (RXCAN), IC2_2551.4 (RXD)
CAN_SS: IC1_2515.16 (CS); also elsewhere on the board
CAN_TXD: IC1_2515.1 (TXCAN), IC2_2551.1 (TXD)
DACA: IC3_4802.8; also elsewhere on the board
DACB: IC3_4802.6; also elsewhere on the board
DAC_SS: IC3_4802.2; also elsewhere on the board
DEBUG_LED: DEBUG.A; also elsewhere on the board
ESTOP_INT: C16.1, R15.1; also elsewhere on the board
GND: C5.2, C6.2, C7.2, C8.2, C9.2, C10.2, C11.2, C12.2, C13.2, C14.2, C16.2, D4.3, IC1_2515.4 (TX0RTS), IC1_2515.5 (TX1RTS), IC1_2515.6 (TX2RTS), IC1_2515.9 (VSS), IC2_2551.2 (VSS), IC3_4802.5, IC3_4802.7, LS1.- (2), R2.1, R9.2, R12.1, R16.2, RESET.1, X4.P$2 (2), X4.P$3 (3); also elsewhere on the board
MISO: IC1_2515.15 (SO); also elsewhere on the board
MOSI: IC1_2515.14 (SI), IC3_4802.4; also elsewhere on the board
unnamed: R11.2, RESET.3 (2)
unnamed: C14.1, R13.2, R14.2
unnamed: DEBUG.K (C), R2.2
unnamed: E-STOP.2, R15.2, R16.1
unnamed: C7.1, R8.1
unnamed: C8.1, R7.1
unnamed: POWER_OK.K (C), R12.2
unnamed: IC2_2551.8 (RS), R9.1
OSC1: C6.1, IC1_2515.8 (OSC1), Q1.2
OSC2: C5.1, IC1_2515.7 (OSC2), Q1.1
RESET: R11.1; also elsewhere on the board
RS: IC1_2515.17 (RESET), R13.1
SCK: IC1_2515.13 (SCK), IC3_4802.3; also elsewhere on the board
WHEELROTATION: C9.1, R17.2, X4.P$1 (1); also elsewhere on the board

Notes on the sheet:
~Latch

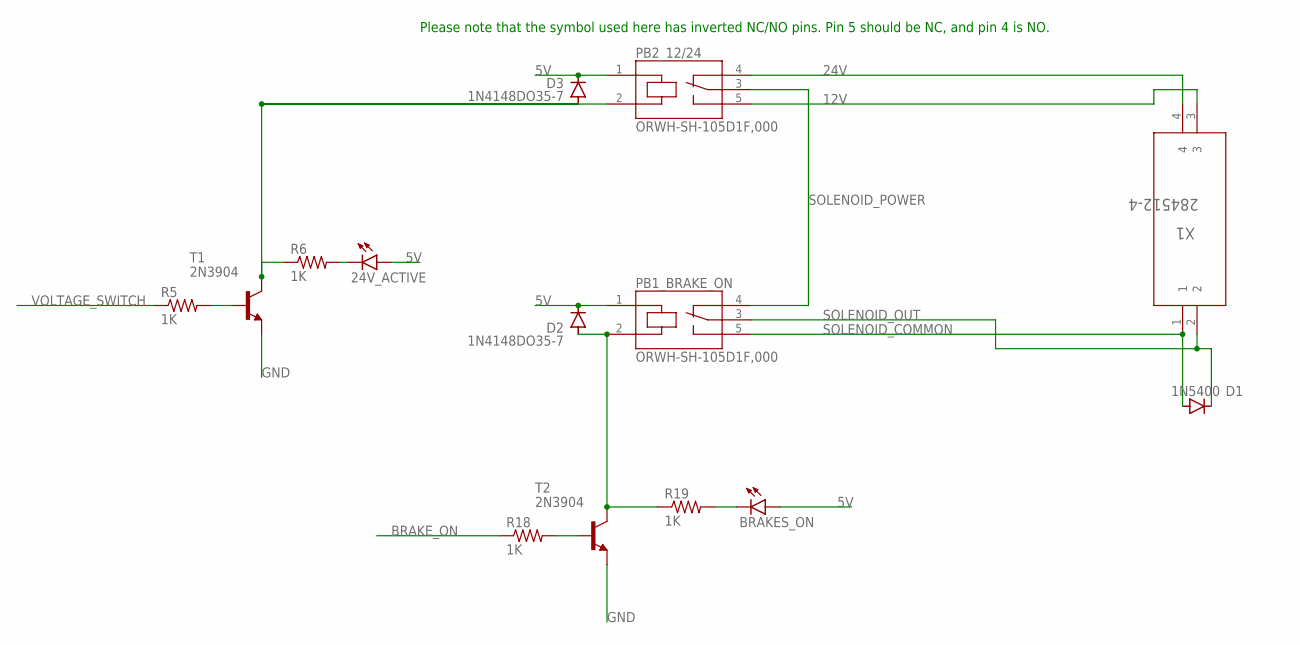
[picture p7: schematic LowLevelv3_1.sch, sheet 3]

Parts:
24V_ACTIVE: LED3MM
BRAKES_ON: LED3MM
D1: 1N5400; DO201-15
D2, D3: 1N4148DO35-7; DO35-7
PB1_BRAKE_ON, PB2_12/24: ORWH-SH-105D1F,000; TE_ORWH-SH-105D1F,000
R5, R6, R18, R19: 1K; R1206
T1, T2: 2N3904; TO92
X1: 284512-4

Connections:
5V: 24V_ACTIVE.A, BRAKES_ON.A, D2.C, D3.C, PB1_BRAKE_ON.1 (C1), PB2_12/24.1 (C1); also elsewhere on the board
12V: PB2_12/24.5 (NO), X1.3
24V: PB2_12/24.4 (NC), X1.4
BRAKE_ON: R18.1; also elsewhere on the board
GND: T1.3 (E), T2.3 (E); also elsewhere on the board
unnamed: R5.2, T1.2 (B)
unnamed: D3.A, PB2_12/24.2 (C2), R6.1, T1.1 (C)
unnamed: 24V_ACTIVE.K (C), R6.2
unnamed: R18.2, T2.2 (B)
unnamed: D2.A, PB1_BRAKE_ON.2 (C2), R19.1, T2.1 (C)
unnamed: BRAKES_ON.K (C), R19.2
SOLENOID_COMMON: D1.A, PB1_BRAKE_ON.5 (NO), X1.1
SOLENOID_OUT: D1.C, PB1_BRAKE_ON.3 (C), X1.2
SOLENOID_POWER: PB1_BRAKE_ON.4 (NC), PB2_12/24.3 (C)
VOLTAGE_SWITCH: R5.1; also elsewhere on the board

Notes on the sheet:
Please note that the symbol used here has inverted NC/NO pins. Pin 5 should be NC, and pin 4 is NO.

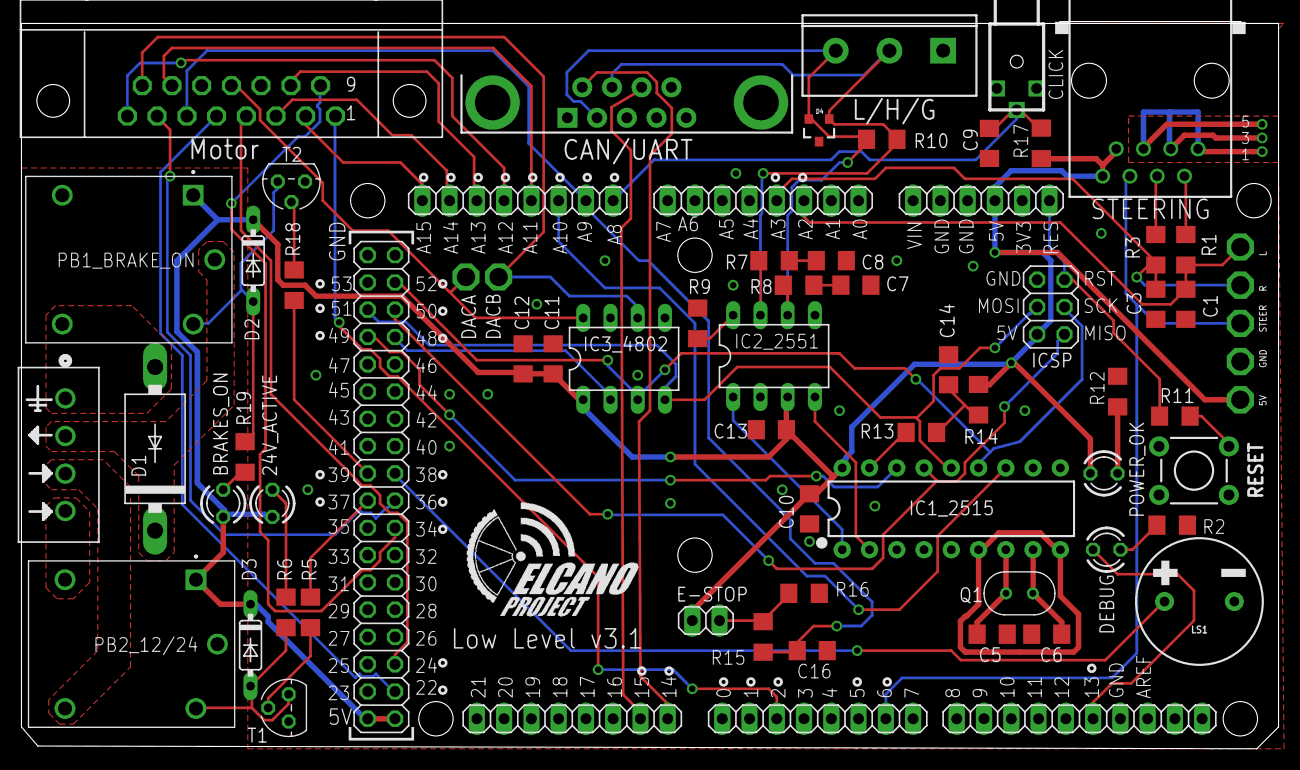
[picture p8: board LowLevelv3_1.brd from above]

Board: 2 copper layers, 117.1 x 67.6 mm, 71 parts (0 on the bottom side), 60 nets.

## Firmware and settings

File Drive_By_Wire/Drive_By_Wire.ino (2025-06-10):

/* Drive_By_Wire
 *  Accept commands over CAN bus
 *  Implement vehicle throttle, brakes and steering as commanded
 *  Report status over CAN bus
 */
#include "DBW_Pins.h"
#include <SPI.h>
#include "Vehicle.h"

#define baud 115200  // baudrate for debugging with a host PC over USB serial

Vehicle *myTrike;

//Timing stuff
#define LOOP_TIME_MS 100
uint32_t nextTime;
uint32_t endTime;
uint32_t delayTime;
#define ULONG_MAX 0x7FFFFFFF

void setup() {
  //analogWriteResolution(12);
  Serial.begin(baud);

  // while(!Serial);

  if (DEBUG) {
    Serial.println("main Setup complete");
  }
  myTrike = new Vehicle();
  myTrike->initalize();
}

void loop() {
  //Timing code
  nextTime = nextTime + LOOP_TIME_MS;
  uint32_t timeStart_ms = millis();

  myTrike->update();

  myTrike->updateRC(); 
  myTrike->LogSD();


  //Timing code
  endTime = millis();
  delayTime = 0UL;
  if ((nextTime >= endTime) && (((endTime < LOOP_TIME_MS) && (nextTime < LOOP_TIME_MS)) || ((endTime >= LOOP_TIME_MS) && (nextTime >= LOOP_TIME_MS)))) {
    delayTime = nextTime - endTime;
    if (nextTime < LOOP_TIME_MS)
      delayTime = ULONG_MAX - endTime + nextTime;
    else {
      nextTime = endTime;
      delayTime = 0UL;
    }
  }
  if (delayTime > 0UL)
    delay(delayTime);

}

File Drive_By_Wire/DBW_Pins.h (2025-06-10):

#ifndef _DBW_PINS_
#define _DBW_PINS_

#define DEBUG false
#define USE_PIDS false // throttle currently uses a PID controller, Steering does not current use a PID controller

#include <Arduino.h>

//Version can be 1,3 or 4; LLB = Low Level Board = Drive By Wire
#define DBWversion 4

/*---------- Version 1 - No Longer supported------------------------
#if DBWversion == 1
//Wheel click interrupt
#define IRPT_WHEEL         3
#define STEER_OUT_PIN      5
#define STEER_ON           8
#define BrakeVoltPin       9
#define BrakeOnPin        10
#define SelectAB          53
#define SelectCD          49
#define DAC_CHANNEL        0
#define AngleSensorLeft   A2
#define AngleSensorRight  A3
*/
/*---------- Version 3: Arduino Mega -------------------------------------*/
#if DBWversion < 4

/* Pin declarations */
// Serial Monitor uses pins 0,1 for RX0,TX0
// Servo to control the brakes; not used

#define BRAKE_PULSE_PIN     2
 // keep-alive watchdog is not yet implemented
#define WATCHDOG_PIN        5  
// Pin used to steer the vehicle with a pulse
#define STEER_PULSE_PIN     6
// Relay that turns on power to the steering system
#define STEER_ON_PIN        8
// Wheel angle sensors mounted on left and right steering columns
#define L_SENSE_PIN    A2
#define R_SENSE_PIN    A3

// Command to e-bike controller to use regenerative braking; not used 
#define REGEN_PIN          22
// Command to e-bike controller to drive in reverse; not used
#define REVERSE_PIN        24
// Switch to drive in forward or reverse; not used
#define FWDSW_PIN          34
#define D_36_PIN           36  // Not used
// Brakes, have relays for both on/off as well as selecting 12/24v power.
#define BrakeVoltPin       37
#define BUZZER_PIN         38  // Not used
#define BrakeOnPin         39

// CANbus slave select
#define CAN_SS_PIN         49  
// SPI chip select for DAC slave select. Channel A is for throttle
#define DAC_SS_PIN         48 
// we only use channel A for the throttle. B is routed but unused.
#define DAC_CHANNEL         0   
// Pins 51,52,53 are MISO, MOSI, SCK.
// originally intended as a return ground, these analog pins are free and on the steering header.
// Intent was to use L_SENSE - L_RTN as a differential signal.
//#define L_RTN_PIN        A6
//#define R_RTN_PIN        A7

/* Signals A8 through A15 are digital interrupts */
/* The Arduino Mega only has 6 interrupts, but an additional 8 can be added through the port pin change interrupt. */
//Wheel click interrupt (digitally high or low, referred to as an "odometer"). Once per wheel revolution.
// IRPT_WHEEL = WHEELROTATION
#define IRPT_WHEEL         A8
// physical E-Stop port; not used
#define IRPT_ESTOP_PIN     A9 
// Interrupt for can msg; not used
#define IRPT_CAN_PIN       A10 

// motor hall phases occur multiple times per wheel revolution
// A future design may make use of these for more precise speed feedback.
// The speedometer_pin would be jumpered to the signal in use
//Not implemented
#define SPEEDOMETER_PIN    A11
#define IRPT_PHASE_C       A12
#define EBIKE_POWER_IN_PIN A13
#define IRPT_PHASE_B       A14
#define IRPT_PHASE_A       A15


/*---------- Version 4: Arduino Due -------------------------------------*/
#else // DBWversion >=4

// Serial Monitor uses pins 0,1 for RX0,TX0
// Pins D0-D13 and A0-A5 are reserved for the Motor Shield
// The shield may block access to A6 and A7.
/*
 *  --------Motor shield pins --------------
 *  Channel A Current sensing   A0
 *  Channel B Current sensing   A1
 *  In2 Connector               A2
 *  In3 Connector               A3
 *  Channel A Speed (PWM)       3
 *  Out5 connector              5
 *  Out6 connector              6
 *  Channel B Brake             8
 *  Channel A Brake             9
 *  Channel B Speed (PWM)       11
 *  Channel A Direection        12
 *  Channel B Direection        13
 *  
 *  Version 4 connectors:
 *  RJ45 Steering: 
 *        L_RTN, L_SENSE, GND, 5V, STEER_PULSE, GND, R_RTN, R_SENSE, GND, 5V
 *  Two 4 wire screw terminals for CAN bus
 *        12V in, GND, CAN LO, CAN HI
 *  One 4 wire screw terminal for brake solenoid
 *        12V in, GND, 24V in, Brake solenoid out (12 or 24V)
 *        The 12V in on this connector is tied to the 12V in on the CAN bus connector,
 *        There should be only one connector to 12V power in, 
 *        A spare 12V connector could be wired to the motor shield, which
 *        already has a common ground.`
 *  One 4 wire screw terminal:
 *        12V out (controlled by STEER_ON), GND, IRPT_WHEEL, GND
 *  RJ45 to e-bike Motor Controller:
 *        FWDSW, EBIKE_POWER_IN, GND, DAC0, DAC1, SPEEDOMETER, WATCHDOG, 
 *        BRAKE_PULSE, REVERSE, REGEN, 

 */
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

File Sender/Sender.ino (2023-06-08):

#include "Can_Protocol.h"

#ifdef __AVR_ATmega2560__ // MEGA
#include <SPI.h>
#include "mcp2515_can.h"
const int CAN_SS_PIN = 49;
mcp2515_can CAN(CAN_SS_PIN);

#else // DUE
#include <due_can.h>
#endif


void setup() {
#ifdef __AVR_ATmega2560__ // MEGA: Setup for CAN

  Serial.begin(115200);
  while (CAN_OK != CAN.begin(CAN_500KBPS, MCP_16MHz)) {
    Serial.println("CAN BUS Shield init fail");
    delay(100);
  }
  Serial.println("CAN BUS init ok!");

#else // DUE: Setup for CAN
  Serial.begin(115200);
  Can0.begin(CAN_BPS_500K);
#endif
}


/*
Arguments for Function:  
currentSpeed: 0 - 255
currentBrake: 0 (release brake), brake > 0 (apply brakes)
currentAngle: Calibration will need to be done/tested again
  - Left: 779 (1ms)
  - Straight: 722 (1.5ms)
  - Right: 639 (1.85ms)
*/
void sendData(int16_t currentSpeed, int16_t currentBrake, int16_t currentAngle) {
  if (currentSpeed < 0 || currentBrake < 0 || currentAngle < 0) {
    return;
  }
  if (currentSpeed > 0 && currentBrake > 0) { // only apply brake if currentSpeed = 0
    currentBrake = 0;  // brakes should not be on, default release brakes
  }

  typedef union {
    struct {
      uint16_t sspeed;
      uint16_t brake;
      uint16_t angle;
      uint16_t reserved;  // not used
    };
  } speedAngleMessage;

  speedAngleMessage MSG;
  MSG.sspeed = currentSpeed;
  MSG.brake = currentBrake;
  MSG.angle = currentAngle;
  MSG.reserved = 0;

#ifdef __AVR_ATmega2560__ // MEGA: Sending CAN Message
  if (CAN_OK == CAN.MCP_CAN::sendMsgBuf(HiDrive_CANID, 0, 8, (uint8_t*)&MSG)) {
    Serial.println("MEGA: Sending Message");
  } else {
    Serial.println("Message failed");
  }

#else // DUE: Sending CAN Message
  CAN_FRAME outgoing;
  outgoing.id = HiDrive_CANID;
  outgoing.extended = false;
  outgoing.length = 8;
  outgoing.data.s0 = MSG.sspeed;
  outgoing.data.s1 = MSG.brake;
  outgoing.data.s2 = MSG.angle;
  if (Can0.sendFrame(outgoing)) {
    Serial.println("DUE: Sending Message");
  } else {
    Serial.println("Message failed");
  }
#endif
}

void loop() {
  //sendData(0,0,0);
  delay(1000);
}

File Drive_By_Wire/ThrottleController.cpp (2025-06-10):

#include <Arduino.h>
#include "DBW_Pins.h"
#if DBWversion < 4
// Only for Arduino Mega
#include <PinChangeInterrupt.h>
#endif  // Mega
#include "ThrottleController.h"
#include "DriveMode.h"


volatile uint32_t ThrottleController::tickTime_ms[2];

ThrottleController::ThrottleController()
  : speedPID(&speedCyclometerInput_mmPs, &PIDThrottleOutput_pwm, &desiredSpeed_mmPs, proportional_throttle, integral_throttle, derivative_throttle, DIRECT) {

  currentThrottlePWM = 0;

  speedPID.SetOutputLimits(MIN_ACC_OUT, MAX_ACC_OUT);
  speedPID.SetSampleTime(PID_CALCULATE_TIME);
  speedPID.SetMode(AUTOMATIC);
  calcTime_ms[0] = 0;
  calcTime_ms[1] = 0;
  prevSpeed_mmPs = 0;

#if DBWversion < 4
  // Only for Arduino Mega
  pinMode(DAC_SS_PIN, OUTPUT);
  SPI.setDataMode(SPI_MODE0);
  SPI.setBitOrder(MSBFIRST);
  SPI.begin();

  if (IRPT_WHEEL != 3)
    attachPCINT(digitalPinToPCINT(IRPT_WHEEL), tick, RISING);
  else
    attachInterrupt(digitalPinToInterrupt(IRPT_WHEEL), tick, RISING);  //pin 3 on Mega
#else    // Due
  attachInterrupt(IRPT_WHEEL, tick, RISING);
#endif  // Mega
  if (DEBUG)
    Serial.println("Throttle Setup Complete");
}

ThrottleController::~ThrottleController() {
}


/*
sets the throttle signal to zero
*/
void ThrottleController::stop() {
  write(DAC_CHANNEL, 0);
  currentThrottlePWM = 0;
}

// not used?
void ThrottleController::tick() {
  uint32_t tick = millis();
  noInterrupts();
  if ((tick - tickTime_ms[0]) > MIN_TICK_TIME_ms) {
    tickTime_ms[1] = tickTime_ms[0];
    tickTime_ms[0] = tick;
  }
  interrupts();
}

/**
 * receives requested speed from Vehicle requested from High Level board
 * attempts to adjust speed either through PIDS or standard engageThrottle() 
 * based on the PIDs being on or off in Settings
 * param dSpeed desired speed in mm/s
 */
int32_t ThrottleController::update(int32_t dSpeed, DriveMode mode) {
  if (mode == NEUTRAL_MODE) {
    stop();  // Disable DAC output
    return 0;
  }

  //Reverse doesnt seem to work
  // if (mode == REVERSE_MODE) {
  //   dSpeed = constrain(dSpeed, 0, 150);  // prevent negatives
  //   dSpeed = map(dSpeed, 0, 150, 150, 0);  // invert DAC for reverse, or just limit
  // }

  if (USE_PIDS)
    ThrottlePID(dSpeed);
  else
    engageThrottle(dSpeed);

  computeSpeed();

  if (DEBUG) {
    Serial.println("mm Speed: " + String(speedCyclometerInput_mmPs));
    Serial.print("PWM speed: ");
    Serial.println(currentThrottlePWM);
  }

  return dSpeed;
}



//Private functions
void ThrottleController::write(int32_t address, int32_t value) {

#if DBWversion < 4
  // Only for Arduino Mega
  int byte1 = ((value & 0xF0) >> 4) | 0x10;  // active mode, bits D7-D4
  int byte2 = (value & 0x0F) << 4;
  if (address < 2) {
    // take the SS pin low to select the chip:
    digitalWrite(DAC_SS_PIN, LOW);
    if (address >= 0) {
      if (address == 1)
        byte1 |= 0x80;  // second channnel
      SPI.transfer(byte1);
      SPI.transfer(byte2);
    }
    // take the SS pin high to de-select the chip:
    digitalWrite(DAC_SS_PIN, HIGH);
  } 
  else {
    // take the SS pin low to select the chip:
    digitalWrite(DAC_SS_PIN, LOW);
    if (address <= 3) {
      if (address == 3)
        byte1 |= 0x80;  // second channnel
      SPI.transfer(byte1);
      SPI.transfer(byte2);
    }
    // take the SS pin high to de-select the chip:
    digitalWrite(DAC_SS_PIN, HIGH);
  }
#else  // Arduino Due

  // Addresss should be 0
  // value is 0 to 4095.
  if (address != 1)
    analogWrite(DAC0, value);
  else
    analogWrite(DAC1, value);

//   if (address != 1)
//   analogWrite(DAC0, map(value, 0, 120, 0, 4095));
// else
//   analogWrite(DAC1, map(value, 0, 120, 0, 4095));
#endif
}



void ThrottleController::ThrottlePID(int32_t desiredValue) {
  if (desiredValue >= (speedCyclometerInput_mmPs + 10)) {
    noInterrupts();
    speedPID.Compute();
    //currentThrottlePWM = (int32_t)PIDThrottleOutput_pwm;
    engageThrottle(PIDThrottleOutput_pwm);
    interrupts();
  }
}

/** 
 *  
 *  @param input desired speed in mm/s
 *  !UPDATE THIS OBSERVED INFO! (LAST UPDATE: May 10, 2013, TCF)
0.831 V at rest 52 counts
1.20 V: nothing 75
1.27 V: just starting 79
1.40 V: slow, steady 87
1.50 V: brisker 94
3.63 V: max 227 counts
255 counts = 4.08 V


Current Calibration: (Last Update: May 14, 2023)
1.187 V: nothing 75
1.20 V: Just starting 82
1.345 V: Slow, steady 85
1.50 V: Briskter, 100
1.85 V: 120 - Maximum Count (for current testing purposes, can extend maximum count)
*/

/* need to fix this function */
void ThrottleController::engageThrottle(int32_t input) {

  // Reset the DAC once if power is off (DAC does not write the same value when PWR is off)
  if (throttleSet == 0) {
    if (DEBUG)
      Serial.println("Reset DAC");
    write(DAC_CHANNEL, 0);
    throttleSet = 1;
  }

  /*  // speedometer, currently not using. 
  int32_t temp = input;
  if (input != 0){
    //needs to be updated, currently this will change the voltage to a desired
    //speed based on starting at 0, it doesn't take into account the current speed of trike
    input = map(input, 0, MAX_SPEED_mmPs, MIN_ACC_OUT, MAX_ACC_OUT);
  }
  */

  if (DEBUG)
    Serial.println("MAPPED speed: " + String(input));

  if (input != currentThrottlePWM) {
    if (input > 255) {
      input = 255;
    } else if (input < 0) {
      input = 0;
    }

    noInterrupts();
    write(DAC_CHANNEL, input);
    currentThrottlePWM = input;  // Remember most recent throttle PWM value.
    interrupts();
  }
}


int32_t ThrottleController::extrapolateSpeed() {
  int32_t y;
  int32_t t = millis();
  //slope calculation
  y = (speedCyclometerInput_mmPs - prevSpeed_mmPs) / (calcTime_ms[0] - calcTime_ms[1]);
  // * change in time
  y *= (t - calcTime_ms[0]);
  // + current speed
  y += speedCyclometerInput_mmPs;

  if (y < 0)
    y = 0;
  return y;
}
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

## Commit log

2020-05-12 Moving library files to compile --> TODO: Consolidate libraries after linking HL/LL/RTR Arduino systems back together
2020-05-22 Fixed #include in vehicle.cpp so the sketch will compile
    [Vehicle.cpp]
2020-05-31 CAN Message update
    Corrected CAN message parsing
    Corrected angle mapping for CAN message.
    [Settings.h, Vehicle.cpp]
2020-08-14 Updated V4 pin numbers; changes for Due
2023-07-01 Settings.h replaced by SettingsTemplate.h and comments added
    [DBW_Pins.h, SettingsTemplate.h, SteeringController.cpp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]
2023-07-01 Settings.h replaced by SettingsTemplate.h
    Comments added. Redundant includes dropped from vehicles.cpp. Added gitignore
    [DBW_Pins.h, SettingsTemplate.h, SteeringController.cpp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]
2024-04-15 New steering and data logging for steering
2024-04-20 Add files via upload
    Using left angle sensor instead of right angle sensor RC commands currently work.
2024-05-20 Datalogger and Steering Software Implemented
    PID controller is not used for Steering or throttle and CAN bus is disabled due to problem with board.
    [DBW_Pins.h, RC_Controller.cpp, SteeringController.cpp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]
2025-03-15 Add files via upload
    This is the updated steering board for the Elcano Drive-by-wire system.
    [SteeringBoard4.1.kicad_pcb, SteeringBoard4.1.kicad_sch]
2025-06-08 Testing Changes
    Includes logging, brakes, throttle, etc
2025-06-09 LowLevel V4.1 PCB Diagram KiCAD + Steering Board.
    These are all the KiCAD, EasyEDA, and LTspice files that our team has modified for DBW V4.1.
    [LowLevelv4_1_1_V2.kicad_sch, LowLevelv4_1_2_V2.kicad_sch, LowLevelv4_1_3_V2.kicad_sch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]
2025-06-09 Updated Changes (6/9/2025)
    Minor fixes
    [RC_Controller.cpp, Vehicle.cpp]
2025-06-09 changes now
    updates to brakes and vehicle
2025-06-09 Updated DBW V4.1 Pin mapping for LowLevel V4.1
    D27 is L_TN and D_29 is R_TN to better fit the operation of the dual steering signal Steering Board V4.1.
    Make any changes to any other signals when necessary. Leave R_TN and L_TN as is.
    [DBW4_1_Pin Mapping_FINAL.xlsx]

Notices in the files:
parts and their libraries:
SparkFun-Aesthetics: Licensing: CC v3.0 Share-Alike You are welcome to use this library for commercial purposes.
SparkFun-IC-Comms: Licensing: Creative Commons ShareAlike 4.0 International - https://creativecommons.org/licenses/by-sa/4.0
